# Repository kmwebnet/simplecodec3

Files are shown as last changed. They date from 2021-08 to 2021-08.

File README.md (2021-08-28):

# Audio input/output board for Raspberry Pi, Jetson Nano (PCM5102A+PCM1808)

This project related to my article.
[Creating an audio input/output board for Raspberry Pi, Jetson Nano (PCM5102A+PCM1808)](https://kentaromitsuyasu.medium.com/creating-an-audio-input-output-board-for-raspberry-pi-jetson-nano-pcm5102a-pcm1808-e3e6f3ad0834)  

In Japanese, [Raspberry Pi, Jetson Nano向けオーディオ入出力ボードの作成(PCM5102A+PCM1808編)](https://qiita.com/kmitsu76/items/07b0bea26ad996e16b30)   

# Environment reference 

This project has tested:  
Raspberry pi 3b  
Raspberry pi 4  
Jetson Nano A02  
Jetson Nano B01  

# Usage

you need to check the driver install instruction for:   
  
[Raspberry pi](https://kentaromitsuyasu.medium.com/creating-an-audio-input-output-board-for-raspberry-pi-jetson-nano-pcm5102a-pcm1808-e3e6f3ad0834)   
    
[Jetson Nano](https://kentaromitsuyasu.medium.com/creating-an-audio-input-output-board-for-raspberry-pi-jetson-nano-porting-trouble-to-jetson-nano-d4674ec4e48e)   

# Notes
You can ignore ATECC608A I2C pattern if you won't use it.

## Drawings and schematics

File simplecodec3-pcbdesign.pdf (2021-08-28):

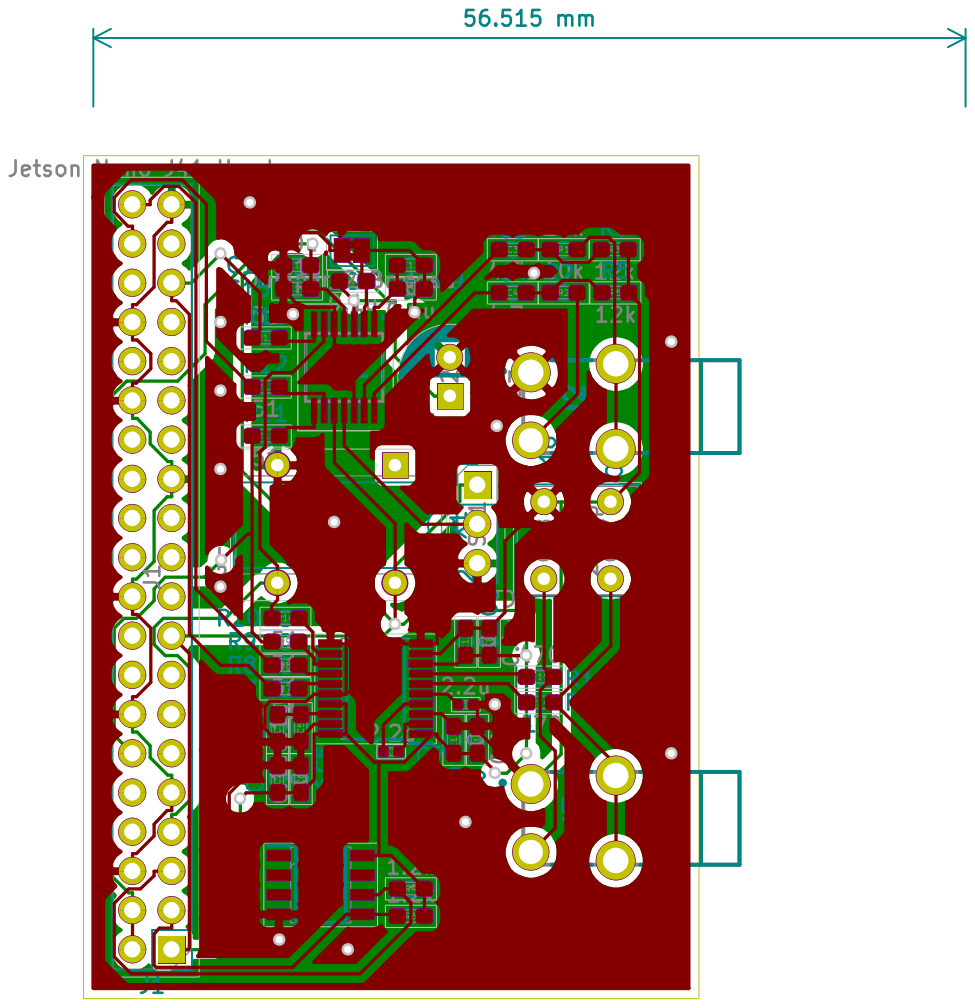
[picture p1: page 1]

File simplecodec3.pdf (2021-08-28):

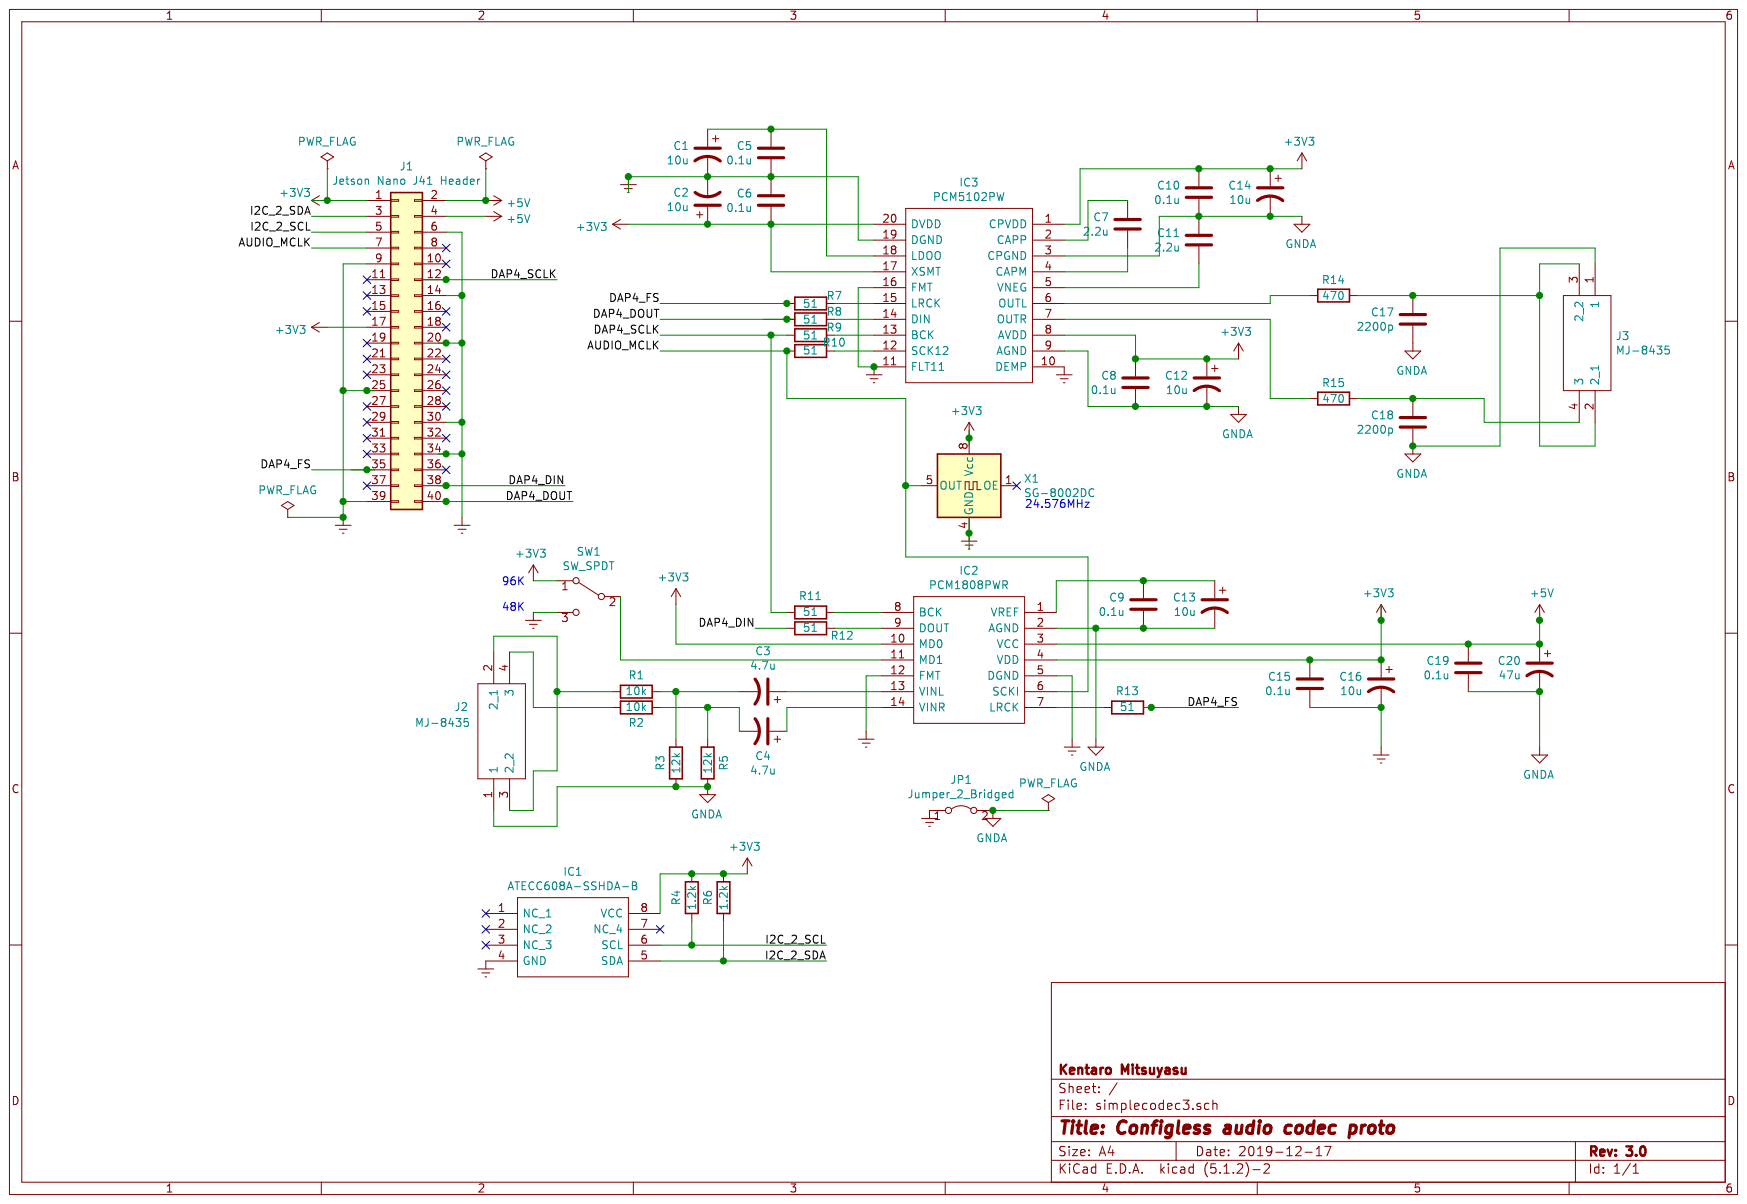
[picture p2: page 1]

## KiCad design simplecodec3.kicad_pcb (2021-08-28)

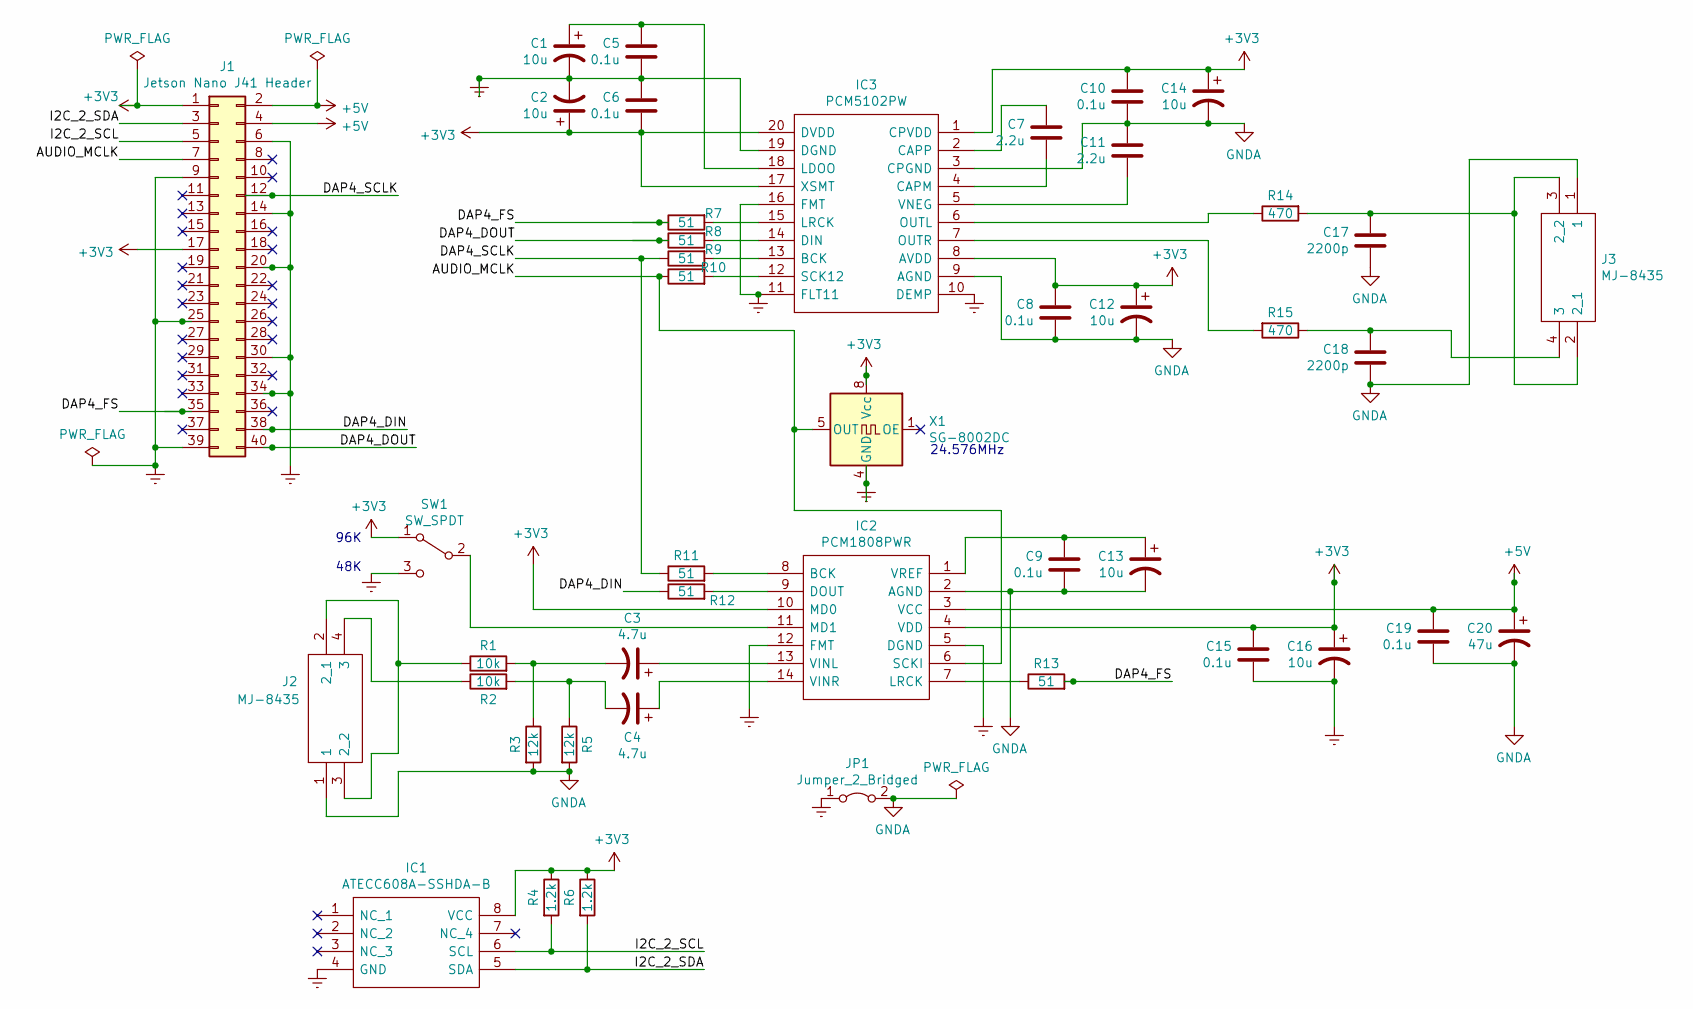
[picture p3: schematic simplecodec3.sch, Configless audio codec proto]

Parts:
C1, C2, C12, C13, C14, C16: 10u; C_0603_1608Metric_Pad1.05x0.95mm_HandSolder
C3, C4: 4.7u; C_0603_1608Metric_Pad1.05x0.95mm_HandSolder
C5, C6, C8, C9, C10, C15, C19: 0.1u; C_0603_1608Metric_Pad1.05x0.95mm_HandSolder
C7, C11: 2.2u; C_0402_1005Metric
C17, C18: 2200p; C_Rect_L7.0mm_W3.5mm_P5.00mm
C20: 47u; CP_Radial_D6.3mm_P2.50mm
IC1: ATECC608A-SSHDA-B; SOIC127P600X175-8N; Manufacturer_Part_Number ATECC608A-SSHDA-B; Mouser Part Number 556-ATECC608ASSHDAB
IC2: PCM1808PWR; Manufacturer_Part_Number PCM1808PWR; Mouser Part Number 595-PCM1808PWR
IC3: PCM5102PW; SOP65P640X120-20N; Manufacturer_Part_Number PCM5102PW; Mouser Part Number 595-PCM5102PW
J1: Jetson Nano J41 Header; PinHeader_2x20_P2.54mm_Vertical
J2, J3: MJ-8435; Manufacturer_Part_Number MJ-8435
JP1: Jumper_2_Bridged; SolderJumper-2_P1.3mm_Bridged2Bar_Pad1.0x1.5mm
R1, R2: 10k; R_0603_1608Metric_Pad1.05x0.95mm_HandSolder
R3, R5: 12k; R_0603_1608Metric_Pad1.05x0.95mm_HandSolder
R4, R6: 1.2k; R_0603_1608Metric_Pad1.05x0.95mm_HandSolder
R7, R8, R9, R10, R11, R12, R13: 51; R_0603_1608Metric_Pad1.05x0.95mm_HandSolder
R14, R15: 470; R_0603_1608Metric_Pad1.05x0.95mm_HandSolder
SW1: SW_SPDT; PinHeader_1x03_P2.54mm_Vertical
X1: SG-8002DC; Oscillator_SeikoEpson_SG-8002DC

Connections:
+3V3: C2.1, C6.2, C8.1, C10.1, C12.1, C14.1, C15.1, C16.1, IC1.8 (VCC), IC2.4 (VDD), IC2.10 (MD0), IC3.1 (CPVDD), IC3.8 (AVDD), IC3.17 (XSMT), IC3.20 (DVDD), J1.1, J1.17, R4.1, R6.1, SW1.1 (A), X1.8 (Vcc)
+5V: C19.1, C20.1, IC2.3 (VCC), J1.2, J1.4
/AUDIO_MCLK: IC2.6 (SCKI), J1.7, R10.1, X1.5 (OUT)
/DAP4_DIN: J1.38, R12.1
/DAP4_DOUT: J1.40, R8.1
/DAP4_FS: J1.35, R7.1, R13.2
/DAP4_SCLK: J1.12, R9.1, R11.1
/I2C_2_SCL: IC1.6 (SCL), J1.5, R4.2
/I2C_2_SDA: IC1.5 (SDA), J1.3, R6.2
Earth: C1.2, C2.2, C5.2, C6.1, C15.2, C16.2, IC1.4 (GND), IC2.5 (DGND), IC2.12 (FMT), IC3.10 (DEMP), IC3.11 (FLT11), IC3.16 (FMT), IC3.19 (DGND), J1.6, J1.9, J1.14, J1.20, J1.25, J1.30, J1.34, J1.39, JP1.1 (A), SW1.3 (C), X1.4 (GND)
GNDA: C8.2, C9.2, C10.2, C11.1, C12.2, C13.2, C14.2, C17.2, C18.2, C19.2, C20.2, IC2.2 (AGND), IC3.3 (CPGND), IC3.9 (AGND), J2.1, J3.1, JP1.2 (B), R3.2, R5.2
unnamed: C1.1, C5.1, IC3.18 (LDOO)
unnamed: C3.1, IC2.13 (VINL)
unnamed: C3.2, R1.2, R3.1
unnamed: C4.1, IC2.14 (VINR)
unnamed: C4.2, R2.2, R5.1
unnamed: C7.1, IC3.2 (CAPP)
unnamed: C7.2, IC3.4 (CAPM)
unnamed: C11.2, IC3.5 (VNEG)
unnamed: C9.1, C13.1, IC2.1 (VREF)
unnamed: C17.1, J3.2 (2_1), J3.3 (2_2), R14.2
unnamed: C18.1, J3.4 (3), R15.1
unnamed: IC2.7 (LRCK), R13.1
unnamed: IC2.8 (BCK), R11.2
unnamed: IC2.9 (DOUT), R12.2
unnamed: IC2.11 (MD1), SW1.2 (B)
unnamed: IC3.6 (OUTL), R14.1
unnamed: IC3.7 (OUTR), R15.2
unnamed: IC3.12 (SCK12), R10.2
unnamed: IC3.13 (BCK), R9.2
unnamed: IC3.14 (DIN), R8.2
unnamed: IC3.15 (LRCK), R7.2
unnamed: J2.2 (2_1), J2.3 (2_2), R1.1
unnamed: J2.4 (3), R2.1

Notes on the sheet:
96K 48K
24.576MHz

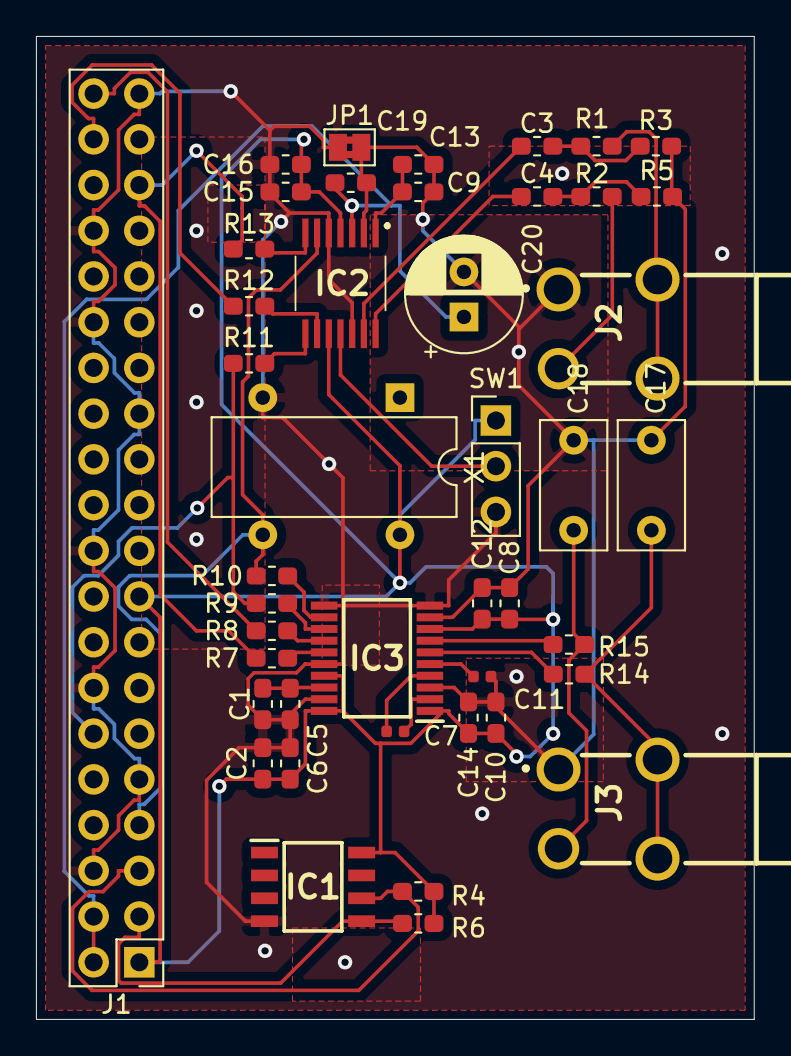
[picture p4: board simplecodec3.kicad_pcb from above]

Board: 2 copper layers, 39.9 x 54.6 mm, 44 parts (0 on the bottom side), 34 nets.

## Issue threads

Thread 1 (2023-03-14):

Jetson Level Shifter

triggerfinger-debug, 2023-03-14:
HI,
would you please share your Jetson Level Shifter Schematic? The picture on your blog I can't read.

kmwebnet, 2023-03-14:
Here you are.
[simplecodec-levelshifter.pdf](https://github.com/kmwebnet/simplecodec3/files/10974348/simplecodec-levelshifter.pdf)

triggerfinger-debug, 2023-03-14:
Thank you :)

Closed 2023-03-14.
